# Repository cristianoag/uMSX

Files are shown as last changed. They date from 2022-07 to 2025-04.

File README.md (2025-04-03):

# uMSX
The uMSX is a MSX2+ FPGA implementation that basically mimics the 1ChipMSX (one of the first FPGA based MSX2+ one chip MSX computers commercially available).

**Please note that the PCB for this project was created by BCH and includes a label explicitly stating that commercial distribution of this work is prohibited. Unfortunately, there have been reports of unauthorized sales of this computer on platforms like Tindie. We kindly ask you to support and reward the original creators of this project, who have generously shared their work with the retro community, rather than those engaging in unauthorized distribution. Thank you for respecting the creators' efforts and intentions.**

The VHDL used is the well known [KDL PLD implementation for the MSX2+](https://github.com/gnogni/ocm-pld-dev) used by the vast majority of the FPGA based MSX computers known. The uMSX uses the first generation of the KDL VHDL source, also known by esemsx.

Based on the already obsolete (but relatively easy to find) Altera EP1C12 FPGA (specifically the EP1C12Q240C8N), the uMSX uses SMD based components (and a few PTH) in a nice compact form factor. It uses the 4 megabit EPCS4 active serial configuration flash memory to host the firmware and configure the FPGA chip at each time the circuit turns on.

A MT48LC16M16A2 SRAM chip offers memory for the computer, which also uses a few other components to implement the clock logic (NC7WV04P6X inverter and 21.47727 basic PTH crystal oscillator) and a 953B voltage detector and reset IC.

Heavily based on 0603 SMT resistance arrays, and other 0805 SMT components, the uMSX is a compact little OCM MSX that can be used to evolve your SMD soldering skills, challenge your knowledge of modern electronics applied to retro computing, and give you a lot of fun through the journey.

## Bill of Materials

### Main Board

<table><thead><tr><th>Qtd</th><th>Part</th><th>Value</th><th>Package</th><th>Type</th><th>Link</th></tr></thead><tbody><tr><td>1</td><td>uMSX main board PCB</td><td>NA</td><td>NA</td><td>NA</td><td><a href="https://www.pcbway.com/project/shareproject/uMSX_A_MSX2_FPGA_implementation_5feda574.html" title="Main Board">Main Board</a></td></tr><tr><td>1</td><td>Custom acrylic box</td><td>NA</td><td>NA</td><td>NA</td><td><a href="https://github.com/cristianoag/uMSX/tree/main/Cases/Acrylic" title="Acrylic Box">Acrylic Box</a></td></tr><tr><td>3</td><td>Nylon pcb standoff</td><td>20mm</td><td>M3</td><td>Black</td><td><a href="https://www.aliexpress.com/item/1005004311987482.html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" title="AliExpress">AliExpress</a></td></tr><tr><td>7</td><td>Nylon screw</td><td>10mm</td><td>M3</td><td>Black</td><td><a href="https://www.aliexpress.com/item/32976116532.html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" title="AliExpress">AliExpress</a></td></tr><tr><td>2</td><td>R106, R96</td><td>10R</td><td>M0805</td><td>SMD Resistor</td><td><a href="https://s.click.aliexpress.com/e/_DCLwtnV" title="AliExpress">AliExpress</a></td></tr><tr><td>1</td><td>R113</td><td>22R</td><td>M0805</td><td>SMD Resistor</td><td><a href="https://s.click.aliexpress.com/e/_DCLwtnV" title="AliExpress">AliExpress</a></td></tr><tr><td>2</td><td>R4, R6</td><td>100R</td><td>M0805</td><td>SMD Resistor</td><td><a href="https://s.click.aliexpress.com/e/_DCLwtnV" title="AliExpress">AliExpress</a></td></tr><tr><td>1</td><td>R7</td><td>1M</td><td>M0805</td><td>SMD Resistor</td><td><a href="https://s.click.aliexpress.com/e/_DCLwtnV" title="AliExpress">AliExpress</a></td></tr><tr><td>2</td><td>R8, R10</td><td>10K</td><td>M0805</td><td>SMD Resistor</td><td><a href="https://s.click.aliexpress.com/e/_DCLwtnV" title="AliExpress">AliExpress</a></td></tr><tr><td>3</td><td>R13A, R13B, R122</td><td>1K</td><td>M0805</td><td>SMD Resistor</td><td><a href="https://s.click.aliexpress.com/e/_DCLwtnV" title="AliExpress">AliExpress</a></td></tr><tr><td>26</td><td>RN133, RN97-101, RN103, RN105, RN108, RN110, RN112, RN114-121, RN123, RN126-127, RN129, RN131, RN135, RN152</td><td>100R</td><td>0603x4 CAY16</td><td>SMD Resistor Array</td><td><a href="https://s.click.aliexpress.com/e/_Ddf4wVz">AliExpress</a></td></tr><tr><td>8</td><td>RN95, RN107, RN109, RN124, RN128, RN130, RN132, RN134</td><td>200R</td><td>0603x4 CAY16</td><td>SMD Resistor Array</td><td><a href="https://s.click.aliexpress.com/e/_Ddf4wVz">AliExpress</a></td></tr><tr><td>5</td><td>RN16, RN111, RN125, RN12, RN13</td><td>1K</td><td>0603x4 CAY16</td><td>SMD Resistor Array</td><td><a href="https://s.click.aliexpress.com/e/_Ddf4wVz">AliExpress</a></td></tr><tr><td>1</td><td>RN94</td><td>10K</td><td>0603x4 CAY16</td><td>SMD Resistor Array</td><td><a href="https://s.click.aliexpress.com/e/_Ddf4wVz">AliExpress</a></td></tr><tr><td>1</td><td>C1</td><td>2.2uf</td><td>C0805</td><td>SMD Ceramic Capacitor</td><td><a href="https://s.click.aliexpress.com/e/_DlXxALh" title="AliExpress">AliExpress</a></td></tr><tr><td>23</td><td>C3-10, C13-15, C21, C23-25, C30-33, C35-37, C134</td><td>100nf</td><td>C0805</td><td>SMD Ceramic Capacitor</td><td><a href="https://s.click.aliexpress.com/e/_DlXxALh" title="AliExpress">AliExpress</a></td></tr><tr><td>2</td><td>C18-19</td><td>27pf</td><td>C0805</td><td>SMD Ceramic Capacitor</td><td><a href="https://s.click.aliexpress.com/e/_DlXxALh" title="AliExpress">AliExpress</a></td></tr><tr><td>8</td><td>C26-28, C18-19, CI10-11, CI16</td><td>220uf 10V</td><td>153CLV-0605</td><td>SMD Electrolytic Capacitor</td><td><a href="https://s.click.aliexpress.com/e/_DFFtZ2j">AliExpress</a></td></tr><tr><td>1</td><td>C34</td><td>4.7uf</td><td>C0805</td><td>SMD Ceramic Capacitor</td><td><a href="https://s.click.aliexpress.com/e/_DlXxALh" title="AliExpress">AliExpress</a></td></tr><tr><td>9</td><td>LED1-9</td><td>Any color</td><td>CHIP-LED0805</td><td>SMD LED</td><td><a href="https://s.click.aliexpress.com/e/_DlAhxEx" title="AliExpress">AliExpress</a></td></tr><tr><td>1</td><td>12V</td><td>1x2</td><td>12v pin to the cartridge board</td><td>Pin Header</td><td><a href="https://s.click.aliexpress.com/e/_DCc67kB" title="AliExpress">AliExpress</a></td></tr><tr><td>1</td><td>JP1</td><td>2x5</td><td>joystick connector</td><td>Pin Header</td><td><a href="https://s.click.aliexpress.com/e/_DeewpBd" title="AliExpress">AliExpress</a></td></tr><tr><td>1</td><td>JP2</td><td>1x2</td><td>on/off switch</td><td>Pin Header</td><td><a href="https://s.click.aliexpress.com/e/_DCc67kB" title="AliExpress">AliExpress</a></td></tr><tr><td>1</td><td>JP3</td><td>2x25</td><td>cartridge board connector</td><td>Pin Header</td><td><a href="https://s.click.aliexpress.com/e/_DeewpBd" title="AliExpress">AliExpress</a></td></tr><tr><td>1</td><td>JP4</td><td>2x5 (10 pin)</td><td>JTAG</td><td>Box Header Connector</td><td><a href="https://s.click.aliexpress.com/e/_DBTGWiB" title="AliExpress">AliExpress</a></td></tr><tr><td>1</td><td>JP5</td><td>3.5mm</td><td>Stereo</td><td>Audio Jack</td><td><a href="https://s.click.aliexpress.com/e/_DmHGVhZ" title="AliExpress">AliExpress</a></td></tr><tr><td>1</td><td>PS2</td><td>6P</td><td>keyboard connector</td><td>PS2</td><td><a href="https://s.click.aliexpress.com/e/_DnDTvyB" title="AliExpress">AliExpress</a></td></tr><tr><td>1</td><td>Q1</td><td>21.47727</td><td>HC49/S</td><td>PTH Crystal Oscillator</td><td><a href="https://s.click.aliexpress.com/e/_DCQxgXh" title="AliExpress">AliExpress</a></td></tr><tr><td>1</td><td>U1</td><td>EPCS4N</td><td>8-pin SOIC</td><td>Active Serial configuration flash</td><td><a href="https://www.aliexpress.com/item/32831351984.html?spm=a2g0o.order_list.0.0.d1da1802R1bdpb" title="AliExpress">AliExpress</a></td></tr><tr><td>1</td><td>U2</td><td>953BFP</td><td>8-pin SOIC</td><td>Voltage detector and reset</td><td><a href="https://s.click.aliexpress.com/e/_DkN7gub" title="AliExpress">AliExpress</a></td></tr><tr><td>1</td><td>U$1</td><td>EP1C12Q240C8N</td><td>240-Pin PQFP</td><td>Cyclone FPGA</td><td><a href="https://s.click.aliexpress.com/e/_DFt3Vzt" title="AliExpress">AliExpress</a></td></tr><tr><td>1</td><td>J1</td><td></td><td></td><td>Micro SD Slot</td><td><a href="https://s.click.aliexpress.com/e/_DCluFa3" title="AliExpress">AliExpress</a></td></tr><tr><td>1</td><td>J2</td><td>DC-005</td><td>Right Angle</td><td>Barrel Power Jack</td><td><a href="https://s.click.aliexpress.com/e/_DEC1UtH" title="">AliExpress</a></td></tr><tr><td>1</td><td>IC1</td><td>MT48LC16M16A2</td><td>TSOP54-400</td><td>SDRAM</td><td><a href="https://s.click.aliexpress.com/e/_DEzMg5d" title="AliExpress">AliExpress</a></td></tr><tr><td>1</td><td>IC2</td><td>3.3v AMS1117</td><td>SOT223</td><td>Voltage Regulator</td><td><a href="https://www.aliexpress.com/item/1005002664829046.html?spm=a2g0o.order_detail.0.0.1788f19c7Qk9pn" title="AliExpress">AliExpress</a></td></tr><tr><td>1</td><td>IC3</td><td>1.5v AMS1117</td><td>SOT223</td><td>Voltage Regulator</td><td><a href="https://www.aliexpress.com/item/1005002664829046.html?spm=a2g0o.order_detail.0.0.1788f19c7Qk9pn" title="AliExpress">AliExpress</a></td></tr><tr><td>1</td><td>IC5</td><td>NC7WZU04P6X</td><td>SOT65P210X110-6AN_SC88_SC70-6</td><td>Dual Unbuffered Inverter</td><td><a href="https://s.click.aliexpress.com/e/_Dmnx4mP" title="AliExpress">AliExpress</a></td></tr><tr><td>1</td><td>RCA</td><td>AV-8.4-5&nbsp;</td><td>RCA</td><td>RCA Connector</td><td><a href="https://www.aliexpress.com/item/1005002282617330.html?spm=a2g0o.order_list.0.0.d1da1802R1bdpb" title="AliExpress">AliExpress</a></td></tr><tr><td>1</td><td>F1</td><td>1.1A</td><td>1812</td><td>PPTC Fuse</td><td><a href="https://s.click.aliexpress.com/e/_Dl7GEh5" title="AliExpress">AliExpress</a></td></tr><tr><td>1</td><td>EDG-08 (SWITCH)</td><td>8 switches</td><td></td><td></td><td><a href="https://s.click.aliexpress.com/e/_DeIVL8P" title="AliExpress">AliExpress</a></td></tr><tr><td>1</td><td>S1 (Button)</td><td>6x6x7 </td><td>Push/Tactile</td><td>Reset Button</td><td><a href="https://s.click.aliexpress.com/e/_DnMVsvd" title="AliExpress">AliExpress</a></td></tr><tr><td>1</td><td>VGA</td><td>DB15</td><td>FEMALE&nbsp;SHORT</td><td>RIGHT ANGLE&nbsp;</td><td><a href="https://s.click.aliexpress.com/e/_DD6B9nl" title="AliExpress">AliExpress</a></td></tr><tr><td>1</td><td>ON/OFF  switch</td><td>2 pin</td><td>21x15</td><td>Boat switch</td><td><a href="https://s.click.aliexpress.com/e/_DFynEar" title="AliExpress">AliExpress</a></td></tr><tr><td>2</td><td>Jumper wire</td><td>Female</td><td>10cm</td><td>ON/OFF cables</td><td><a href="https://s.click.aliexpress.com/e/_DneiqIB" title="AliExpress">AliExpress</a></td></tr><tr><td>2</td><td>Spade Crimp Terminals and Sleeves</td><td>Female</td><td>4.8mm</td><td>(Buy the set)</td><td><a href="https://www.aliexpress.com/item/33048405492.html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" title="AliExpress">AliExpress</a></td></tr><tr><td>1</td><td>Socket Connector </td><td>Female</td><td>2.54MM Pitch</td><td>Joystick cable connector</td><td><a href="https://s.click.aliexpress.com/e/_DdWEL91" title="AliExpress">AliExpress</a></td></tr><tr><td>1</td><td>Flat Ribbon Cable</td><td>10P (10 pins)</td><td></td><td>Joystick cable</td><td><a href="https://s.click.aliexpress.com/e/_DegaOLh" title="AliExpress">AliExpress</a></td></tr><tr><td>1</td><td>DB9 male connector</td><td>9 pin</td><td></td><td>Joystick cable connector</td><td><a href="https://s.click.aliexpress.com/e/_DeWE3Fz" title="AliExpress">AliExpress</a></td></tr><tr><td>1</td><td>microSD/TF card</td><td>4GB</td><td></td><td>Memory card</td><td><a href="https://s.click.aliexpress.com/e/_DlS57W7" title="AliExpress">AliExpress</a></td></tr></tbody></table>

### Cartridge Board

<table><thead><tr><th>Qtd</th><th>Part</th><th>Value</th><th>Package</th><th>Type</th><th>Link</th></tr></thead><tbody><tr><td>1</td><td>uMSX cartridge board PCB</td><td>NA</td><td>NA</td><td>NA</td><td><a href="https://www.pcbway.com/project/shareproject/uMSX_A_MSX2_FPGA_implementation_5feda574.html" title="Cartridge Board">Cartridge Board</a></td></tr><tr><td>1</td><td>TMA_0512D</td><td>12V</td><td></td><td></td><td><a href="https://s.click.aliexpress.com/e/_DdxjSqf" title="AliExpress">AliExpress</a></td></tr><tr><td>2</td><td>Inductor</td><td>100uf</td><td>PTH</td><td></td><td><a href="https://s.click.aliexpress.com/e/_DmAOSjp" title="AliExpress">AliExpress</a></td></tr><tr><td>2</td><td>Electrolytic Capacitor</td><td>10uf/25V</td><td>153CLV-0605</td><td>SMD </td><td><a href="https://s.click.aliexpress.com/e/_Dmfm8KX" title="AliExpress">AliExpress</a></td></tr><tr><td>1</td><td>Electrolytic Capacitor</td><td>100uf/16V</td><td>153CLV-0605</td><td>SMD</td><td><a href="https://s.click.aliexpress.com/e/_Dmfm8KX" title="AliExpress">AliExpress</a></td></tr><tr><td>3</td><td>Ceramic Capacitor</td><td>100nf</td><td>C0805</td><td>SMD </td><td><a href="https://s.click.aliexpress.com/e/_DlXxALh" title="AliExpress">AliExpress</a></td></tr><tr><td>2</td><td>Ceramic Capacitor</td><td>4.7uf</td><td>C0805</td><td>SMD </td><td><a href="https://s.click.aliexpress.com/e/_DlXxALh" title="AliExpress">AliExpress</a></td></tr><tr><td>2</td><td>Resistor</td><td>2K</td><td>M0805</td><td>SMD</td><td><a href="https://s.click.aliexpress.com/e/_DCLwtnV" title="AliExpress">AliExpress</a></td></tr><tr><td>1</td><td>Main board connector</td><td>2x25</td><td></td><td>Pin Header</td><td><a href="https://s.click.aliexpress.com/e/_DeewpBd" title="AliExpress">AliExpress</a></td></tr><tr><td>2</td><td>Edge card connector</td><td>50P</td><td></td><td>Cartridge</td><td><a href="https://s.click.aliexpress.com/e/_DBeJZ51" title="AliExpress">AliExpress</a></td></tr><tr><td>4</td><td>PCB metal standoff</td><td>15-20mm</td><td>M3</td><td>Standoff</td><td><a href="https://s.click.aliexpress.com/e/_DdNrijD" title="AliExpress">AliExpress</a></td></tr><tr><td>4</td><td>Silicone cap</td><td>13mm</td><td>M3</td><td>Sleeve/cap</td><td><a href="https://s.click.aliexpress.com/e/_DlMdjAx" title="AliExpress">AliExpress</a></td></tr><tr><td>4</td><td>Nut</td><td></td><td>M3</td><td>Nut</td><td><a href="https://s.click.aliexpress.com/e/_Dk687gr" title="AliExpress">AliExpress</a></td></tr><tr><td>1</td><td>Main board cable</td><td>20cm</td><td>50P 2x25P</td><td>Flat cable</td><td><a href="https://www.aliexpress.com/item/1005001609304753.html?spm=a2g0o.order_list.0.0.21ef1802pojAjg" title="AliExpress">AliExpress</a></td></tr></tbody></table>

## References
* Original thread (in Spanish) with details about the project [uMSX: Clon MSX2+ FPGA](https://www.va-de-retro.com/foros/viewtopic.php?f=63&t=6655)

* Article (in English) with details on how to build, BoM, tips and tricks [Yet another FPGA based MSX (The uMSX)](https://theretrohacker.com/2022/07/08/yet-another-fpga-based-msx-the-umsx/)

* Youtube video (in Portuguese) with additional details [YouTube Video](https://www.youtube.com/watch?v=aj3B5qDagoM)

## License 

Open Hardware

This work is licensed under a [Creative Commons Attribution-NonCommercial-ShareAlike 4.0 International License](http://creativecommons.org/licenses/by-nc-sa/4.0/).

* If you remix, transform, or build upon the material, you must distribute your contributions under the same license as the original.
* You may not use the material for commercial purposes.
* You must give appropriate credit, provide a link to the license, and indicate if changes were made. You may do so in any reasonable manner, but not in any way that suggests the licensor endorses you or your use.

**ATTENTION**

This project was made for the retro community and not for commercial purposes. So only retro hardware forums and individual people can build this project.

THE SALE OF ANY PART OF THIS PROJECT WITHOUT EXPRESS AUTHORIZATION IS PROHIBITED!

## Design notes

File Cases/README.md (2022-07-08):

# Cases for the uMSX
* Acrylic - Corel draw 21 and 18 for case designs in 3mm acrylic. I also exported SVG files in case you have issues opening the Corel files. I opted for not use the cartridge box design.
* Caja uMSX FreeCad - This is a FreeCAD design for a case that can be 3D printed. 
* uMSX_case.zip - 3D printer case for the uMSX

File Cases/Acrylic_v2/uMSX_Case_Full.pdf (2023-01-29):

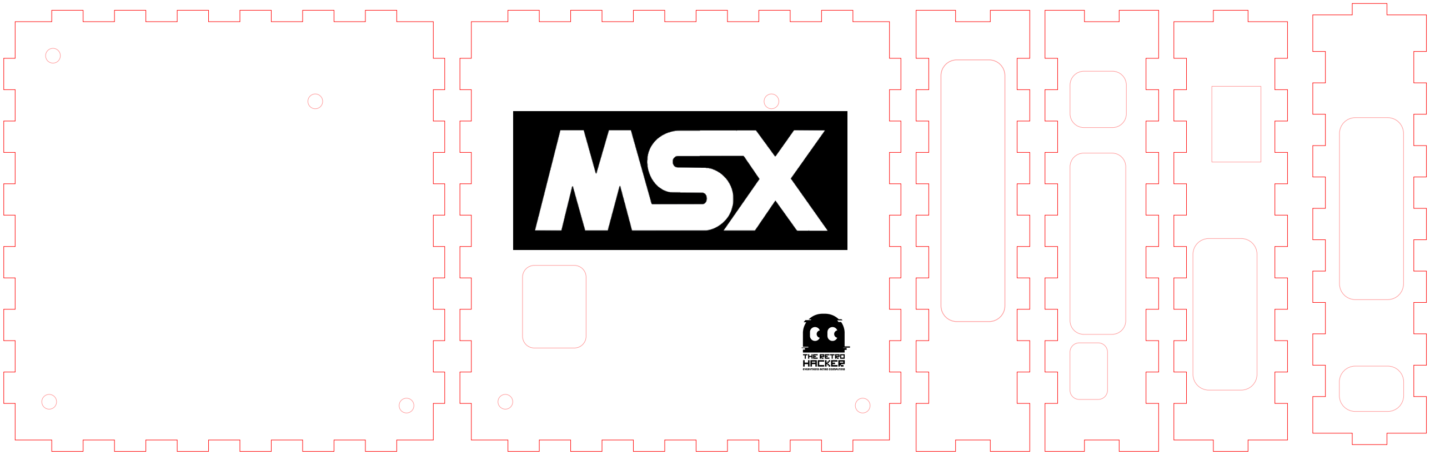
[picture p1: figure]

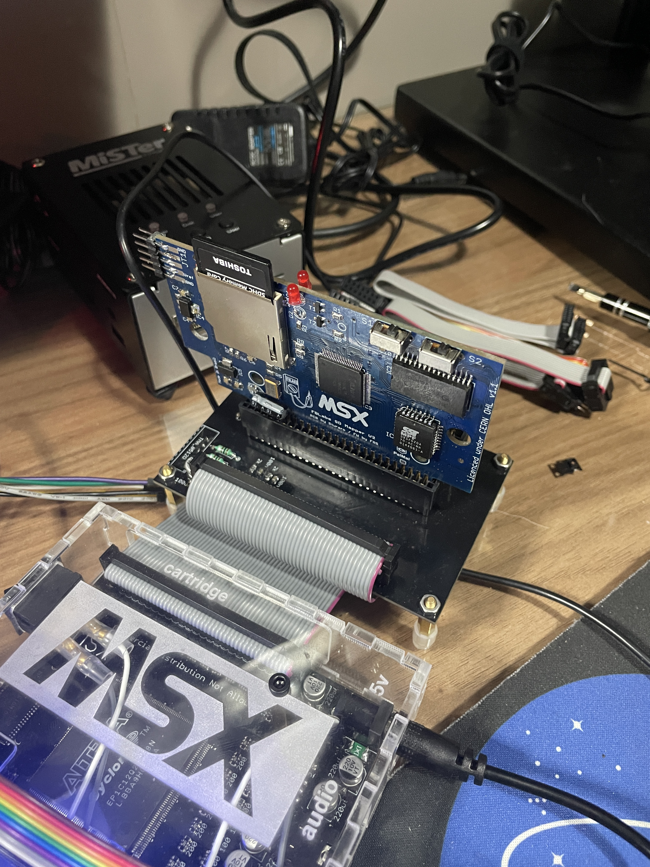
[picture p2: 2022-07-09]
Images/20220626_212402626_iOS.jpg

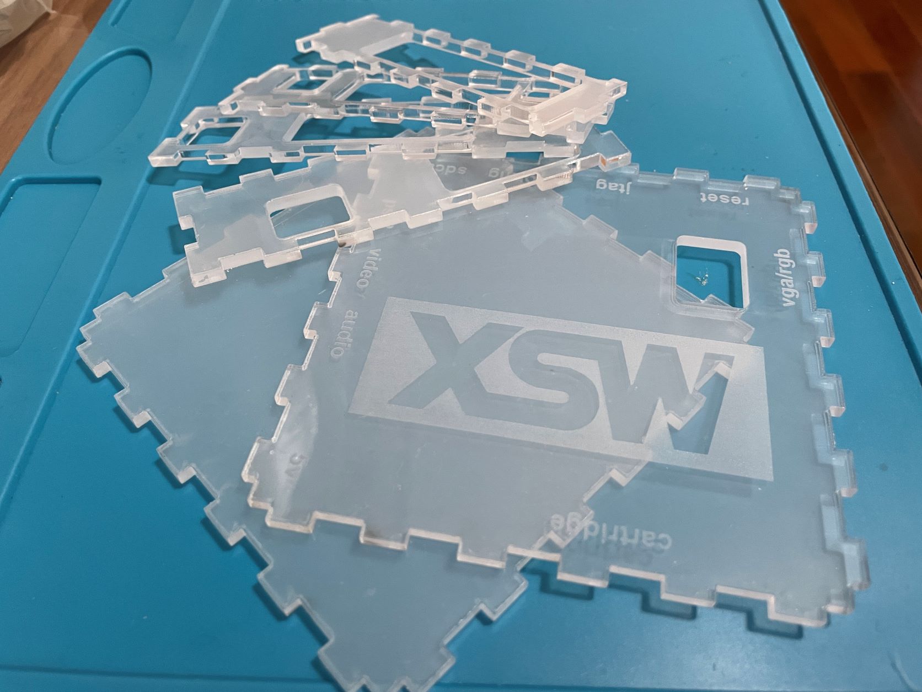
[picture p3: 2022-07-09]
Images/20220708_163719724_iOS.jpg

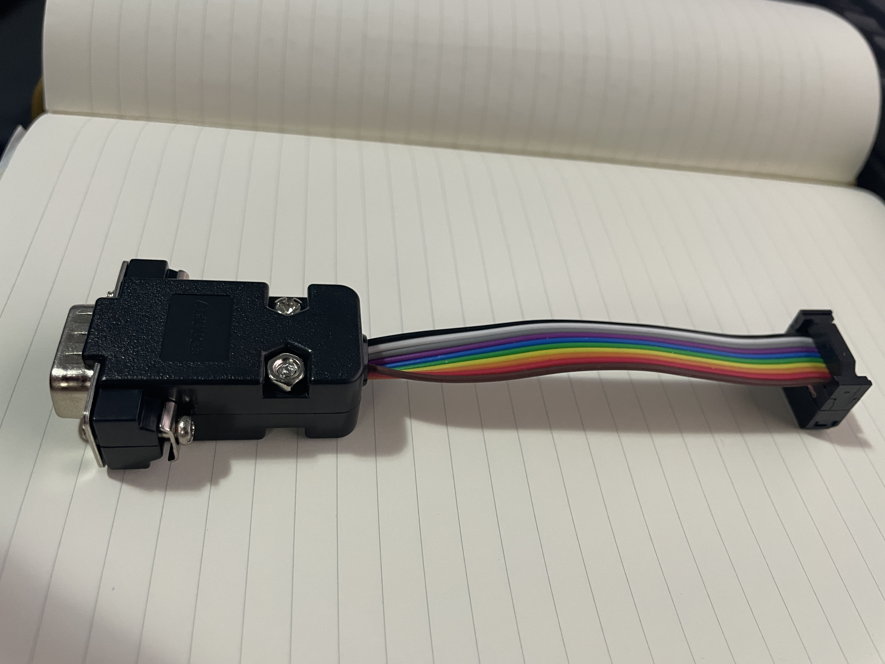
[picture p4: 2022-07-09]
Images/20220707_235009077_iOS.jpg

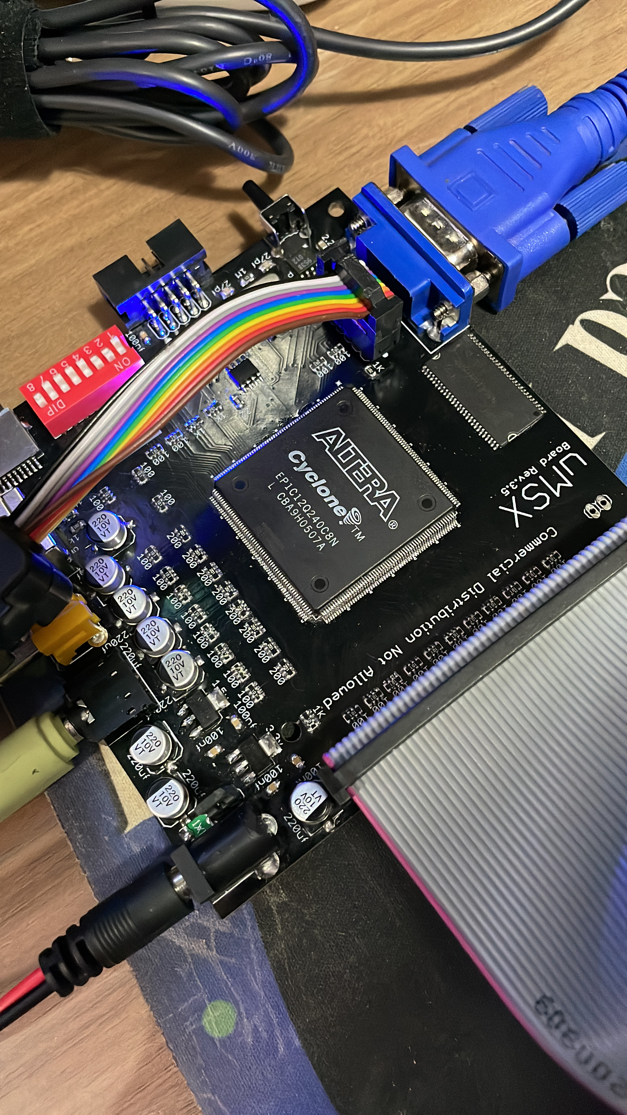
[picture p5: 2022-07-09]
Images/20220603_183352433_iOS.jpg

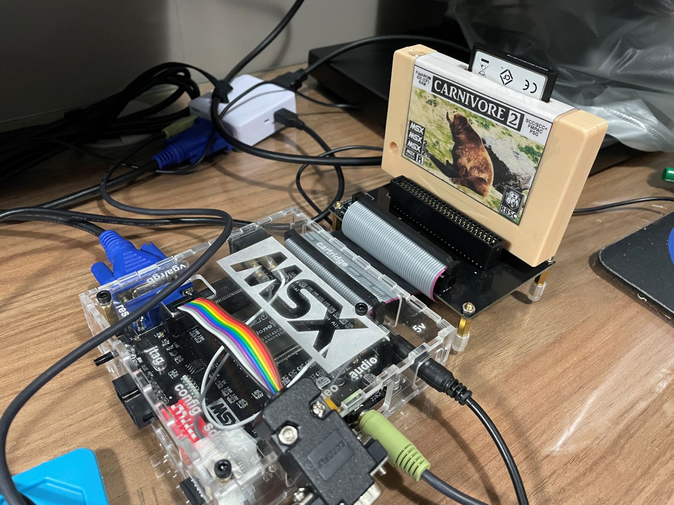
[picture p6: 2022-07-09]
Images/20220619_215049823_iOS.jpg

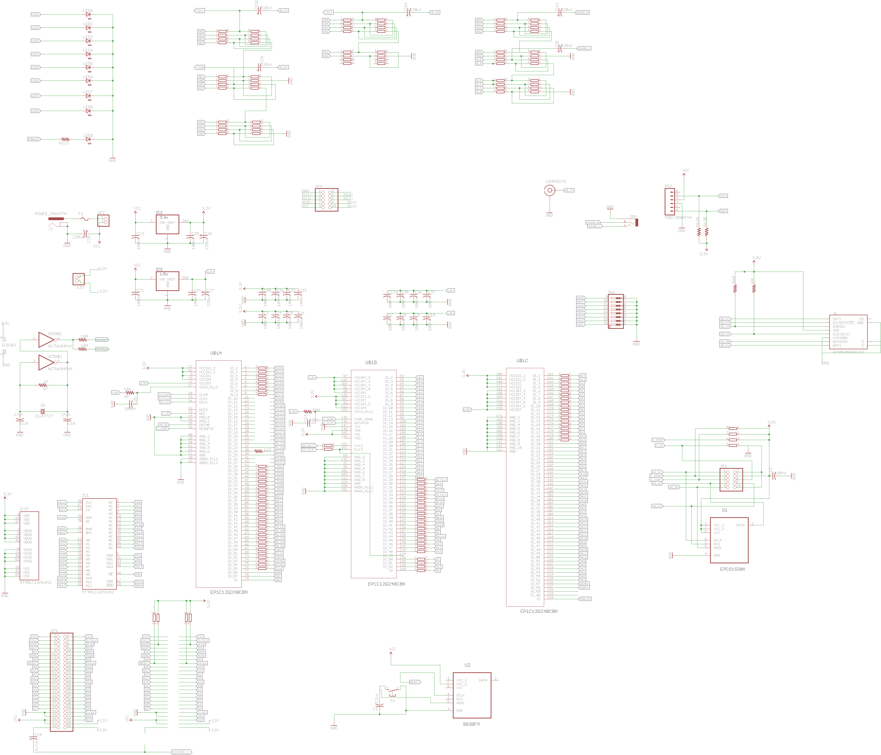
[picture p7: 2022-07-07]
Schemas/OCM_Schema.png

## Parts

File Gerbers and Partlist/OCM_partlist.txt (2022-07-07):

Partlist

EAGLE Version 6.5.0 Copyright (c) 1988-2013 CadSoft

Assembly variant: 

Part      Value              Package                        Library                     Position (mm)         Orientation

12V                          1X02                           pinhead                     (31.75 84.75)         R0
R106      10                 M0805                          resistor                    (46.22 18.49)         R90
R113      22                 M0805                          resistor                    (69.78 26.76)         R270
RN133     100                CAY16                          resistor-dil                (100.03 60.665)       R270
C1        2.2uf              C0805                          adafruit                    (36.67 10.07)         R90
C3        100nf              C0805                          adafruit                    (79.15 67.05)         MR0
C4        100nf              C0805                          adafruit                    (68.99 67.05)         MR270
C5        100nf              C0805                          adafruit                    (65.18 67.05)         MR270
C6        100nf              C0805                          adafruit                    (57.56 67.05)         MR270
C7        100nf              C0805                          adafruit                    (55.02 45.46)         MR180
C8        100nf              C0805                          adafruit                    (55.02 51.81)         MR180
C9        100nf              C0805                          adafruit                    (55.02 58.16)         MR180
C10       100nf              C0805                          adafruit                    (55.02 63.24)         MR180
C13       100nf              C0805                          adafruit                    (76.03 3.78)          R270
C14       100nf              C0805                          adafruit                    (62.465 75.705)       MR180
C15       100nf              C0805                          adafruit                    (41.18 18.99)         R90
C18       27pf               C0805                          adafruit                    (47.7 6.23)           R0
C19       27pf               C0805                          adafruit                    (57.37 6.23)          R180
C21       100nf              C0805                          adafruit                    (110.96 77.9)         R180
C23       100nf              C0805                          adafruit                    (106.61 88.86)        R180
C24       100nf              C0805                          adafruit                    (105.11 76.41)        R90
C25       100nf              C0805                          adafruit                    (100.72 88.01)        R90
C26       220uf              153CLV-0605                    adafruit                    (121.21 80.24)        R90
C27       220uf              153CLV-0605                    adafruit                    (118.31 71.76)        R90
C28       220uf              153CLV-0605                    adafruit                    (102.73 95.31)        R270
C30       100nf              C0805                          adafruit                    (57.56 41.65)         MR90
C31       100nf              C0805                          adafruit                    (63.91 41.65)         MR90
C32       100nf              C0805                          adafruit                    (74.07 41.65)         MR90
C33       100nf              C0805                          adafruit                    (79.15 41.65)         MR0
C34       4.7uf              C0805                          adafruit                    (39.69 83.28)         R180
C35       100nf              C0805                          adafruit                    (79.15 61.97)         MR0
C36       100nf              C0805                          adafruit                    (79.15 55.62)         MR0
C37       100nf              C0805                          adafruit                    (79.15 50.54)         MR0
C134      100nf              C0805                          adafruit                    (79.15 45.46)         MR0
CI8       220uf              153CLV-0605                    adafruit                    (107.96 56.19)        R180
CI9       220uf              153CLV-0605                    adafruit                    (108.92 41.37)        R180
CI10      220uf              153CLV-0605                    adafruit                    (103.71 34.54)        R180
CI11      220uf              153CLV-0605                    adafruit                    (107.96 48.99)        R180
CI16      220uf              153CLV-0605                    adafruit                    (108.17 63.49)        R180
COMPOSITE RCA                RCA                            uzebox                      (120.7 44.79)         R270
F1                           1812                           adafruit                    (120.07 86.58)        R180
IC1       MT48LC16M16A2-6A   TSOP54-400                     memory-micron               (32.41 54.35)         R270
IC2       3.3v               SOT223                         burr-brown                  (105.82 82.78)        R90
IC3       1.5v               SOT223                         burr-brown                  (108.42 71.05)        R90
IC5       NC7WV04P6X         SOT65P210X110-6AN_SC88_SC70-6  fairchild-tinylogic         (53.25 18.75)         R90 (ou SN74LVC2G04DCKR)
J1        ATTEND-MICROSD-112 ATTEND-112                     sd-mmc                      (111.75 4.75)         R0
J2        POWER_JACKPTH      POWER_JACK_PTH                 SparkFun-Connectors copy    (125.059103125 92.892028125) R90
JP1                          2X05                           pinhead                     (67.51 3.8)           R180
JP2                          1X02                           pinhead                     (113.68 86.23)        R180
JP3                          2X25                           pinhead                     (65.25 95.75)         R180
JP4                          2X05                           pinhead                     (43 29.5)             R270
JP5                          SPARKFUN-CONNECTORS_AUDIO-JACK zxuno_v41                   (121.5 60)            R180
LED1                         CHIP-LED0805                   adafruit                    (67.25 16.25)         R180
LED2                         CHIP-LED0805                   adafruit                    (69 16.25)            R180
LED3                         CHIP-LED0805                   adafruit                    (70.75 16.25)         R180
LED4                         CHIP-LED0805                   adafruit                    (72.5 16.25)          R180
LED5                         CHIP-LED0805                   adafruit                    (74.25 16.25)         R180
LED6                         CHIP-LED0805                   adafruit                    (76 16.25)            R180
LED7                         CHIP-LED0805                   adafruit                    (77.75 16.25)         R180
LED8                         CHIP-LED0805                   adafruit                    (79.5 16.25)          R180
LED9                         CHIP-LED0805                   adafruit                    (81.25 16.25)         R180
PS2       MINI-DIN6PTH       MINI-DIN6                      SparkFun-Connectors         (124.75 28.96)        R270
Q1        21.47727           HC49/S                         adafruit                    (53.09 11.35)         R180
R4        100                M0805                          resistor                    (49.49 18.67)         R270
R6        100                M0805                          resistor                    (56.45 18.83)         R90
R7        1M                 M0805                          resistor                    (52.66 6.07)          R0
R8        10k                M0805                          resistor                    (115.16 18.11)        R0
R10       10k                M0805                          resistor                    (120.93 18.14)        R180
R13A      1k                 M0805                          resistor                    (107.86 28.8)         R180
R13B      1k                 M0805                          resistor                    (107.86 25.99)        R180
R96       10                 M0805                          resistor                    (65.89 76.635)        MR270
R122      1K                 R0603                          adafruit                    (46.13 37.84)         R90
RN16      1K                 CAY16                          resistor-dil                (95.05 83.67)         R270
RN94      10K                CAY16                          resistor-dil                (62.1 13.59)          R270
RN95      200                CAY16                          resistor-dil                (93.1975 47.194375)   R270
RN97      100                CAY16                          resistor-dil                (44.75 87.25)         R0
RN98      100                CAY16                          resistor-dil                (48.75 30.25)         R0
RN99      100                CAY16                          resistor-dil                (49.135 87.25)        R0
RN100     100                CAY16                          resistor-dil                (53 30.25)            R0
RN101     100                CAY16                          resistor-dil                (53.52 87.25)         R0
RN103     100                CAY16                          resistor-dil                (57.905 87.25)        R0
RN105     100                CAY16                          resistor-dil                (62.29 87.25)         R0
RN107     200                CAY16                          resistor-dil                (93.084375 74.178125) R270
RN108     100                CAY16                          resistor-dil                (99.76 47.27)         R270
RN109     200                CAY16                          resistor-dil                (93.276875 42.273125) R270
RN110     100                CAY16                          resistor-dil                (66.675 87.25)        R0
RN111     1K                 CAY16                          resistor-dil                (74.329375 25.221875) R0
RN112     100                CAY16                          resistor-dil                (71.06 87.25)         R0
RN114     100                CAY16                          resistor-dil                (75.445 87.25)        R0
RN115     100                CAY16                          resistor-dil                (83.75 25.25)         R0
RN116     100                CAY16                          resistor-dil                (79.83 87.25)         R0
RN117     100                CAY16                          resistor-dil                (88.185 25.31)        R0
RN118     100                CAY16                          resistor-dil                (84.215 87.25)        R0
RN119     100                CAY16                          resistor-dil                (93.095 27.785)       R90
RN120     100                CAY16                          resistor-dil                (88.6 87.25)          R0
RN121     100                CAY16                          resistor-dil                (100.335 27.115)      R90
RN123     100                CAY16                          resistor-dil                (99.853125 42.249375) R270
RN124     200                CAY16                          resistor-dil                (93.005 51.675)       R270
RN125     1K                 CAY16                          resistor-dil                (79.06375 25.34875)   R0
RN126     100                CAY16                          resistor-dil                (99.76 51.81)         R270
RN127     100                CAY16                          resistor-dil                (99.734746875 74.093796875) R270
RN128     200                CAY16                          resistor-dil                (92.985625 69.4275)   R270
RN129     100                CAY16                          resistor-dil                (99.732221875 69.655228125) R270
RN130     200                CAY16                          resistor-dil                (93.005 64.915)       R270
RN131     100                CAY16                          resistor-dil                (99.9988125 65.01619375) R270
RN132     200                CAY16                          resistor-dil                (93.005 60.7)         R270
RN134     200                CAY16                          resistor-dil                (92.88 56.243125)     R270
RN135     100                CAY16                          resistor-dil                (99.72563125 56.380725) R270
RN152     100                CAY16                          resistor-dil                (93.25 34.785)        R90
S1                           B3F-31XX                       adafruit                    (40.64 3.55)          R0
SW1                          EDG-08                         special                     (90.62 6.05)          R0
U$1       EP1C12Q240C8N      QFP50P3460X3460X410-240N       Altera_By_element14_Batch_1 (67.72 54.35)         R90
U1        EPCS4N             SOIC127P600X175-8N             Altera_By_element14_Batch_1 (65.26 22.69)         R90
U2        953BFP             SOIC127P600X175-8N             Altera_By_element14_Batch_1 (42 10.5)             R90

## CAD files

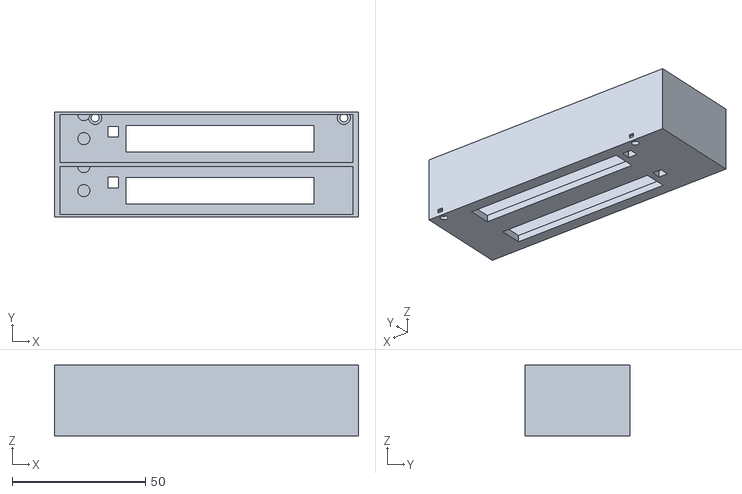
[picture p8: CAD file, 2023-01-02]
Cases/uMSX Slot Guide.stl
114.0 x 39.5 x 26.6

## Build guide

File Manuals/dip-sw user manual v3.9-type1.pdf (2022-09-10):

# DIP-SW User Manual

## for 1chipMSX, Zemmix Neo, SX-1 and related (Cyclone I series)

## OCM-PLD Pack v3.9 by KdL

DIP-SW | FUNCTION | STATUS | DESCRIPTION
| | OFF | Standard mode 3.58MHz
| 1 | CPU Clock | ON | Custom Speed mode 4.10MHz to 8.06MHz (10.74MHz on system bus) • Press [F12] key to change clock type (3.58MHz >> 5.37MHz >> Custom Speed) • The external clock is set on [Sync to CPU] by default • [Turbo Pana] is 5.37MHz like the original specification • A special hybrid clock [Turbo MegaSD] is enabled by default
| | | OFF / OFF | Composite / S-Video • 15kHz, 50Hz+60Hz, interlaced video signal
| 2 / 3 | Video Output | OFF / ON | RGB w/ Audio Out (a mono signal inside the video cable) • 15kHz, 50Hz+60Hz, interlaced video signal, requires a VGA to SCART cable
| | | ON / OFF | VGA Mode for LED TV or LED Display • Progressive video signal 31kHz / 50Hz+60Hz with the ability to set the pixel ratio 1:1 at 60Hz
| | | ON / ON | VGA+ Mode for CRT Monitor (legacy output) (hardware scanlines on Zemmix Neo) • Progressive video signal 31kHz / 50Hz+60Hz / SETSMART -D0 must be executed to force 60Hz
| | | OFF | External Slot-1 • Advised like default
| 4 | Cartridge Slot-1 | ON | Internal ESE-MegaSCC+ 1024kB (shared w/ the 2nd half of ESE-MegaSCC+ Slot-2) • External Slot-1 is disabled • Memo: the CMT toggle is [Scroll Lock] key (disabled by default)
| | | OFF / OFF | External Slot-2 • Advised like default
| 5 / 6 | Cartridge Slot-2 | OFF / ON | Internal ESE-MegaRAM ASCII-8K 1024kB • External Slot-2 is disabled
| | | ON / OFF | Internal ESE-MegaSCC+ 2048kB • External Slot-2 is disabled
| | | ON / ON | Internal ESE-MegaRAM ASCII-16K 2048kB • External Slot-2 is disabled
| 7 | Internal Mapper | OFF | Internal 2048kB RAM • Advised like default
| | | ON | Internal 4096kB RAM
| | | OFF | Disabled
| 8 | Internal MegaSD | ON | Enabled • Advised like default

## KdL Index! < https://gnogni.altervista.org >

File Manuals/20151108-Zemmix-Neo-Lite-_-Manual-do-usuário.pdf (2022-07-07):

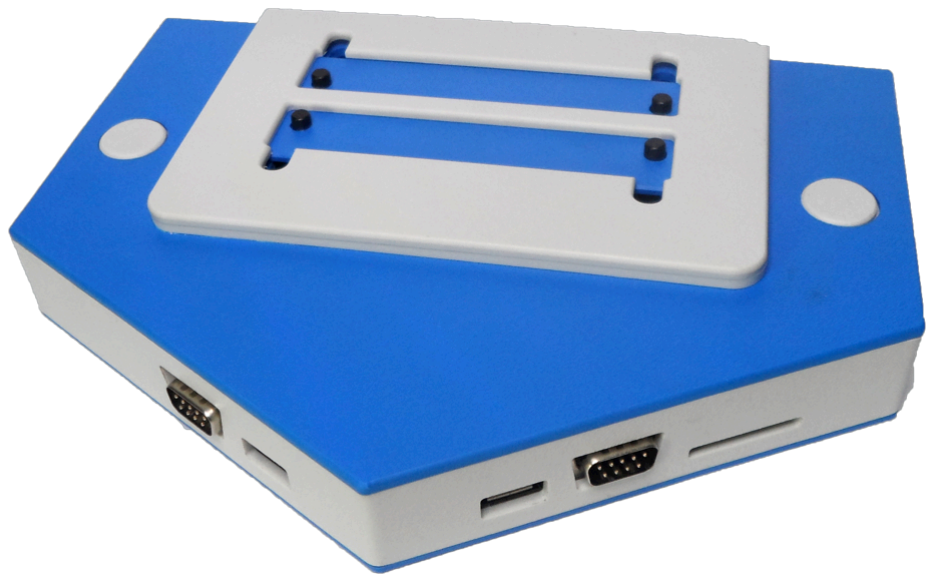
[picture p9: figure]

# Zemmix Neo Lite BR Edition Manual do Usuário

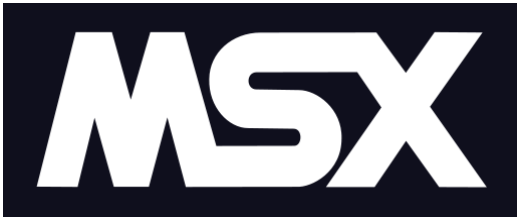
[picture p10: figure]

A obra Zemmix Neo Lite BR Edition - Manual do Usuário de Bruno Nazareth está licenciado com uma Licença Creative Commons -Atribuição-NãoComercial 4.0 Internacional. Baseado no trabalho disponível em mailto: brnazareth em gmail ponto com.

## Índice

## 1. O que é o MSX (definição da Wikipedia)

MSX é o nome de uma arquitetura padrão para computadores pessoais, lançada pela Microsoft em 16 de junho de 1983 e concebido por Kazuhiki Nishi, vice-presidente da Microsoft Japão e diretor da ASCII Corporation. Diz-se que a Microsoft liderou o projeto como uma tentativa de criar um padrão unificado para os fabricantes de hardware. Apesar do envolvimento da Microsoft, computadores baseados no MSX raramente são vistos nos Estados Unidos, mas foram populares em países como Japão, Oriente Médio, Brasil, União Soviética, Holanda, Espanha e menor volume em diversos países europeus. É difícil estimar quantos computadores MSX foram vendidos mundialmente, mas eventualmente 5 milhões de unidades foram vendidas apenas no Japão.

## 2. Sobre o Zemmix Neo

O Zemmix Neo é um hardware baseado na placa e código fonte do One Chip MSX (OCM). Basicamente, foram implementadas todas as funcionalidades do OCM e acrescentado um gerador de scanlines. Possui ainda suporte a teclados USB que emulem o padrão PS2.

## 3. Especificações

- Compatível com MSX2+
- Turbo de 8MHz
- 4 Megabytes de Mapper e 1 Megabyte de ESE-MegaRAM
- Saída VGA 15/31KHz
- Saídas de Vídeo Composto, S-Video
- Cartão SD (até 2GB em FAT16)
- Teclado PS/2 e USB
- 2 Slots para cartuchos
- Áudio Estéreo
- FM
- 1MB ESE-RAM SCC+
- Entrada para Cassete

## 4. Diagrama físico

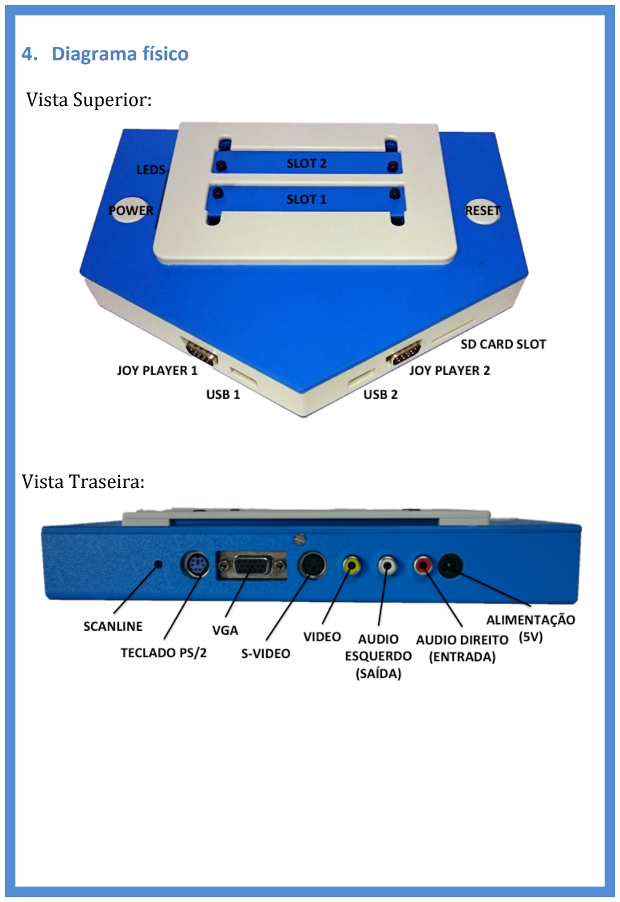
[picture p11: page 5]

Vista Superior:

Vista Traseira:

## 5. Como Ligar Seu Zemmix Neo

Antes de ligar seu Zemmix Neo, efetue as seguintes conexões:
1) Alimentação: a fonte deve ser de 5 volts e 2 ampéres. O polo positivo é o pino central.
2) Video: para melhor qualidade de imagem é recomendado utilizar a saída de video VGA. O Zemmix Neo, diferentemente de computadores MSX clássicos, suporta qualquer monitor equipados com este tipo de conector. Caso sua televisão não suporte essa entrada, prefira SVIDEO e por último o conector de VIDEO (amarelo).
3) Audio: conecte as saídas de audio direita e esquerda a uma caixa de som amplificada ou uma mesa/amplificador externo. Caso sua televisão não suporte audio stereo, utilize apenas o conector de saída de audio esquerdo (branco).
4) Teclado: a porta USB 2 suporta utilização de teclados que emulem o protocolo PS/2. Teclados reconhecidos como HID (Human Interface Device) não são suportados. Teclados padrão PS/2 também podem ser utilizados no conector traseiro do Zemmix Neo.
5) Cartuchos ROM ou Cartão SD: Insira os cartuchos ROM ou o cartão SD nos slots.

ATENÇÃO: Remover qualquer conexão ou dispositivo de armazenamento com seu Zemmix Neo ligado pode danifica-lo. Desligue sempre o Zemmix Neo antes de fazer qualquer alteração.

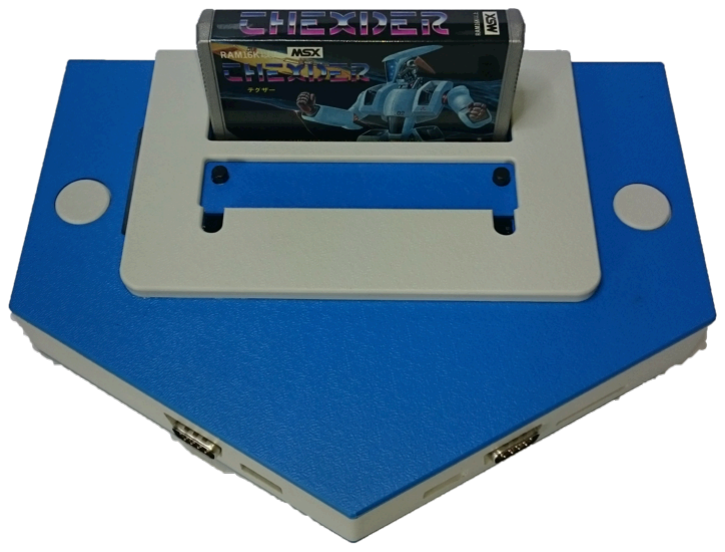
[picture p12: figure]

## 6. Configurações de Dip Switches

Switch | Função | Estado | Explicação
SW1 | Velocidade CPU | Desligado | Modo 3,58 MHz
| | Ligado | Velocidade personalizada (8,06MHz) - Modo TurboPANA é 5,37MHz - Turbo MegaSD é habilitado como padrão
SW2/SW3 | Saída de Vídeo | Desligado/Desligado | Modo Video Composto/S-Video (15KHz Interlaçado, 50/60Hz)
| | Desligado/Ligado | RGB-Audio Mono (15KHz, vídeo Interlaçado, 50/60Hz, SCART, Aúdio mono no conector VGA)
| | Ligado/Desligado | VGA brilho normal (31KHz progressivo, 60Hz somente)
| | Ligado/Ligado | VGA com scanlines (31KHz progressivo, 50/60Hz)
SW4 | Configuração Slot 1 | Desligado | Usar Slot 1 externo
| | Ligado | Modo ESE MegaSCC+ interna (1024KB) - Slot 1 externo desabilitado
SW5/SW6 | Configuração Slot 2 | Desligado/Desligado | Usar Slot 2 externo
| | Desligado/Ligado | Modo ESE MegaRAM interna [ASCII-8KB-BANK] (1024KB) - Slot 2 externo desabilitado
| | Ligado/Desligado | Modo ESE MegaSCC+ interna (1024KB) - Slot 2 externo desabilitado
| | Ligado/Ligado | Modo ESE MegaRAM interna [ASCII-16KB-BANK] (1024KB) - Slot 2 externo desabilitado
SW7 | Memory Mapper | Desligado | RAM interna de 2048KB
| | Ligado | RAM interna de 4096KB
SW8 | Cartão SD | Desligado | Desabilitado
| | Ligado | Ligado

Exemplo de dip switches (recomendada por padrão):
- Ligadas: 1, 2, 3 e 8
- Desligadas: 4, 5, 6, 7

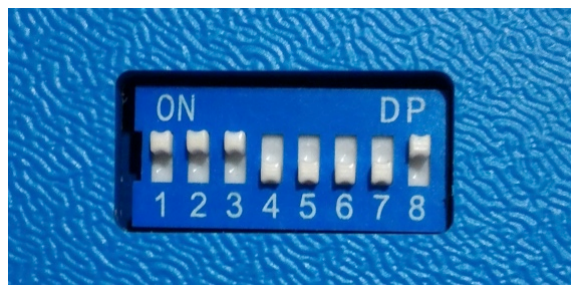
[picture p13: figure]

## 7. Atalhos de teclado

O Zemmix Neo suporta teclados PS/2 ou USB que emule comandos PS/2. Algumas teclas de um MSX tradicional foram mapeadas para serem adequadas aos teclados modernos. Existem também algumas teclas e combinações que podem ser utilizadas para alterar as configurações de hardware do Zemmix Neo:

Tecla ou Combinação | Função
END | Tecla STOP do MSX.
ALT | Tecla GRAPH do MSX.
WIN | Tecla SPACE do MSX.
F6 | Tecla GRAPH do MSX.
F7 | Tecla KANA do MSX.
F8 | Tecla SELECT do MSX.
F9 | Aumenta o volume do PSG.
SHIFT + F9 | Abaixa o volume do PSG.
F10 | Aumenta o volume do SCC.
SHIFT + F10 | Abaixa o volume do SCC.
F11 | Aumenta o volume do OPL.
SHIFT + F11 | Abaixa o volume do OPL.
PAGE UP | Aumenta o volume geral.
PAGE DOWN | Abaixa o volume geral.
F12 | Altera o clock da CPU entre 3 valores: 3,58MHz, 5,37MHz, ou Personalizado 8MHz.
PRINTSCREEN | Altera o tipo de saída de vídeo na sequencia: CVBS/S-Video, SCART, VGA 31KHz, VGA+ 31KHz.
SHIFT + PRINTSCREEN | Altera o tipo de saída de vídeo na sequencia: VGA+ 31KHz , VGA 31KHz, SCART, CVBS/S-Video.
SCROLL LOCK | Ativa ou desativa o modo Cassete.
SHIFT + F12 | Altera a configuração do SLOT 1: externo/SCC+.
SHIFT + SCROLL LOCK | Altera a configuração do SLOT 2: externo/ASCII8/SCC+/ASCII16.

## 8. Leds de Status

Os LEDs indicam algumas configurações atuais. Os LEDs Verdes são numerados de 1 a 8 no sentido de cima para baixo e o Vermelho é o 9. Durante os ajustes de volume os LEDs são usados para indicar o nível de volume, no estilo Bargraph. Após um tempo os LEDs voltam à indicar as configurações atuais:

Led | Status | Status
1 | Piscando | Atividade no Cartão SD ou memória Flash.
2 | Apagado Aceso | Memória Mapper a 2MB. Memoria Mapper a 4MB.
3/4 | Apagado/Apagado Apagado/Aceso Aceso/Apagado Aceso/Aceso | SLOT 2 Externo Ativo ESE-MegaRAM ASCII 8K Ativa ESE-MegaSCC+ Ativa ESE-MegaRAM ASCII 16K Ativa
5 | Apagado Aceso | SLOT 1 Externo Ativo ESE-SCC+ Ativa
6/7 | Apagado/Apagado Apagado/Aceso Aceso/Apagado Aceso/Aceso | Modo Vídeo Composto / S-Video Modo RGB-Audio(SCART) Modo VGA brilho normal Modo VGA com scanlines
8/9 | Apagado/Apagado Apagado/Aceso Aceso/Apagado | Clock de 3.58 MHz Clock de 5.37 MHz Clock Custom

No teclado os LEDs também são indicadores para alguns estados:
- LED Scroll Lock: modo cassete ativado;
- LED: Num Lock: modo Kana ativado.

## 9. Execução de Programas no Zemmix Neo

## 9.1.Como usar cartuchos ROM MSX

Os dois slots do Zemmix Neo podem ser utilizados para executar cartuchos ROM. Para ativar o slot 1 é necessário manter a dip switch 4 desligada. Para ativar o slot 2, desligue as dip switches 5 e 6.
Após alterar as configurações das dip switches, basta inserir o cartucho e ligar o Zemmix Neo.

ATENÇÃO: Não insira ou remova os cartuchos com o Zemmix Neo Ligado!

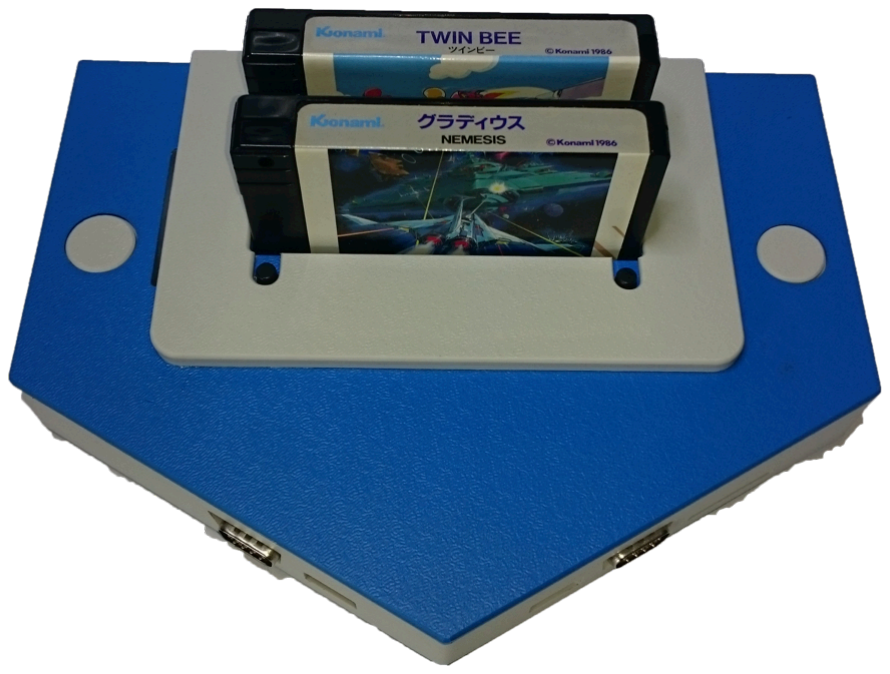
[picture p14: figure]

## 9.2.Uso de drive externo

Além de alterar as dip switches para habilitar os slots para Interface de drive externo, é necessário ainda desabilitar o leitor de cartões SD que pode interferir no funcionamento:

1. Desligue a dip switch 8. (Quando a dip switch 8 está ligada significa habilitar o cartão de leitor SD e pode gerar erros com o FDD)
2. Insira a interface de drive no slot - Pode ser utilizado qualquer slot. Certifique-se que está bem encaixado.
3. Ligar o Zemmix Neo

Caso tenha um disco inserido no drive, ele será lido. Caso contrário será exibida a tela de Disk BASIC.

## 9.3.Uso de gravador de dados

É possível ligar um gravador de fitas cassete ao Zemmix Neo:

1. Desligue a dip switch 8 para usar o gravador de dados.
2. Ligar o Zemmix Neo e apertar a tecla Scroll Lock uma vez.
3. Ligar o gravador no conector RCA VERMELHO. Esse conector é compartilhado como entrada e saída K7.
4. Inserir o comando adequado.

Após a exibição da tela de BASIC, entre com o comando CLOAD (Pode ser utilizado BLOAD, RUN de acordo com o manual de instruções da fita cassete). Não existe conexão “remote” no Zemmix Neo, portanto é requerido pressionar os botões play/stop/record no gravador manualmente.

## 9.4.Uso de cartão SD

É possível utilizar cartões SD como armazenamento de programas executáveis, arquivos ROM, arquivos DSK e etc. O Zemmix Neo aceita cartões de no máximo 2GB formatados apenas em FAT16.

ATENÇÃO: O Zemmix Neo não é compatível com cartões SDHC e não suporta cartões maiores que 2GB.

1. Certifique-se que o cartão utilizado é compatível com o Zemmix Neo.
2. Ligue a dip switch 8 com o Zemmix Neo desligado.
3. Insira o cartão SD no Zemmix Neo. Será escutado um clique quando o cartão estiver conectado corretamente.

4. Use o cartão SD como um dispositivo de armazenamento em massa.

Após a inicialização, será exibida a tela do Disk BASIC. Podem ser utilizados os comandos de BASIC para manipulação de arquivos (FILES, SAVE, LOAD, etc…) para controlar o cartão SD. Normalmente, o cartão SD é reconhecido como drive A. Caso exista uma interface de disco externa conectada, o cartão será reconhecido como drive C.

5. Uso do MSX-DOS2: Os arquivos MSXDOS2.SYS e COMMAND2.COM podem ser copiados para o cartão SD. É possível encontrar esses arquivos em repositórios na Internet.
6. Uso do ROMLOAD: Arquivos ROM podem ser executados através do comando romload <arquivo .rom>. Os arquivos ROM podem ser executados em conjunto com a emulação da SCC+ e MegaRAM controladas através das dip switches 4, 5 e 6.
7. Uso do MGLOCM: Arquivos ROM podem ser executados através do comando mglocm <arquivo .rom> com configuração automática dos periféricos internos.

Para remover o cartão SD, desligue o Zemmix Neo e pressione o cartão. Será ouvido um clique quando o cartão for ejetado.

ATENÇÃO: O LED 8 piscará quando o cartão SD estiver em uso. O cartão pode ser danificado se removido ou o Zemmix Neo com o cartão estiver em uso. Verifique se o cartão está em uso antes de remove-lo.

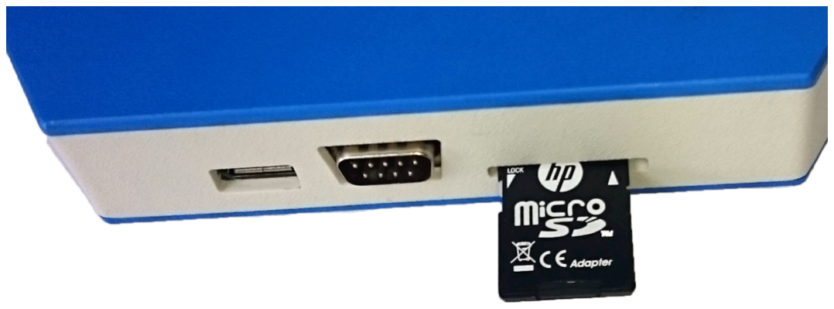
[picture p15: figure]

## 9.5.Execução de discos de jogos (Uso do ep.com)

### 1. Jogos multi-disco (Exemplo: YS 2)

Copie as imagens de disco YS21.DSK e YS22.DSK para o cartão SD (no mesmo diretório).

Execute o comando “ep YS2*.DSK /b /r” na linha de comando.

É possível alterar o disco com o atalho F7+Enter e depois pressione o número do disco (0 a 9).

### 2. Jogos de um disco como Age of Discovery (Jogos da Koei)

Acrescente as seguintes linhas ao Autoexec.bat:

set shell=b:\command.com
path b:\

Copie o arquivo Dai.dsk (imagem do Age of Discovery) e o reboot.com para o cartão SD.

Execute o comando “ep DAI.DSK a:” e execute “reboot.com” a partir do drive A.

É possível salvar status dos jogos em disco. Também pode utilizar uma PAC ou FM-PAC. Alguns jogos que verificam “S-RAM” não podem ser salvos na PAC ou FM-PAC.

ATENÇÃO: Este método de troca de discos não funciona para jogos do tipo “3 Kingdoms”.

### 3. Snatcher, SD-Snatcher ou Konami Game Collections

Ligue a dip switch 5, desligue a dip switch 6 (ESE-SCC+) no Zemmix Neo e execute o comando ep para o arquivo em questão.

## 9.6.Execução de jogos Megarom

1. Usar o romload.com para jogos megarom.
Execute o comando “romload ROM_NAME.rom /r /s” com a dip switch 5 ligada e a 6 desligada.

Se o arquivo ROM não for executado, é possível abrir o arquivo romload.lst para validar as opções do romload. O romload.com possui uma configuração interna para permitir a execução de Konami SCC, Konami4 (Metal Gear 1 e 2, Maze of Galious, etc…), ASCII (Bubble Bobble), ASC16K (Aleste).
2. Usar Ngload para carregar jogos megarom.
Altere as dip switches no Zemmix Neo para cada tipo de cartucho:
5 desligado, 6 ligado: ESE-ASCII 8K
5 ligado, 6 desligado: ESE-SCC+
5 ligado, 6 ligado: ESE-ASCII 16K

Execute o comando “ngload ROM_NAME /r”.

É necessário alterar a extensão do arquivo ROM. Por exemplo, Konami SCC deve ser alterado para SCK/SKN/ROM, Konami 4 alterado para KNM, ASC 8k alterado para 8K e ASC 16K alterado para 16K.
É necessário alterar a mapper megarom em conjunto com as dip switches do Zemmix Neo.

### 3. Jogos Koei 4M

Desligue a dip switch 5 e ligue a 6 (ESE-ASCII 8K).

Ao executar uma ROM Koei 4M será exibido na tela “S-RAM check”. É possível executar o jogo e salvar na PAC ou FM-PAC. Não funciona para todos os jogos da Koei.

### 4. MGLOCM

Outra opção é usar o utilitário MGLOCM.COM. Deixe as dip switches 4, 5 e 6 desligadas, execute o comando “mglocm ROMFILE.ROM” e o utilitário irá reconhecer o formato da ROM, configurar os slots de acordo com o necessário e executar o jogo.
ATENÇÃO: Ao executar o MGLOCM os slots externos podem ser desativados para a ativação dos periféricos internos, causando travamento se houver algum cartucho de armazenamento em massa sendo utilizado.

## 10.Solução de problemas

Verifique essas soluções caso encontre problemas.

Problema: O Zemmix Neo não liga.
- O cabo de força está ligado corretamente?
- A Fonte é compatível? O Zemmix Neo suporta alimentação de 5 volts com até 2 ampéres e polo positivo no centro. Apesar de funcionar, não é recomendado a alimentação pelas portas USB pois não existem proteções contra surtos de energia nessas entradas.

O Zemmix Neo está ligado mas não exibe nada na tela.
- Está ligado corretamente na TV? O conector de video no Zemmix Neo é igual ao da TV (amarelo).
- O conector/cabo não está com defeito?
- A lâmpada de status acende corretamente?
- Alguns monitores VGA não suportam a saída do Zemmix neo. Tente utilizar as saídas S-video ou A/V.
- Através das combinações das dip switches 2 e 3 é possível trocar os modos de exibição. Se a tela não exibir nada e não for detectado um problema de hardware, verifique as configurações das dip switches.

ATENÇÃO: Não utilize mais de uma saída de video simultaneamente. Isso pode danificar seu Zemmix Neo.

O teclado não funciona
- O teclado está conectado na porta PS/2 ou na porta USB da direita? O conector USB da esquerda não pode ser utilizado para teclado. A maioria dos teclados USB podem ser utilizados com o Zemmix Neo, mas alguns teclados não são compatíveis com a conexão PS/2. Tente um outro teclado.
- O Zemmix Neo utiliza algum teclado especial?
O Zemmix Neo utiliza o teclado padrão ABNT. Se forem pressionadas múltiplas teclas, algumas podem ser reconhecidas erroneamente.

O cartucho de ROM não funciona.
- O cartucho não está sujo? Limpe o cartucho e o slot se o cartucho não funcionar.
- Alguns cartuchos precisam ser iniciados com a tecla shift pressionada.

- Mesmo se for inserido o cartucho no Zemmix Neo com as configurações das dip switches corretas, pode ser exibida a tela do BASIC ou gráficos distorcidos. Pode ser por causa de sujeira no slot para cartuchos. É necessário proceder com a limpeza do slot.
Para limpar o slot, pode utilizar um cotonete embebido com um pouco de álcool isopropílico ou etanol. Espere secar antes de utilizar o slot.

Programa no disco não funciona
- O disco não está danificado?
- O Software no disco é compatível com MSX/MSX2/MSX2+? O Zemmix Neo é compatível com MSX2+, entretanto, não é possível garantir 100% de compatibilidade. Software de Turbo-r não é compatível.
- A leitura de discos pode ser afetada caso a cabeça de leitura esteja suja. É necessário utilizar um disco de limpeza para corrigir o problema.

Cartão SD não funciona
- A dip switch 8 está desligada? O Zemmix Neo pode ter sido enviado da “fábrica” com a dip switch desligada.
- O cartão está formatado com FAT16? Utilize este programa para formatar o cartão SD (o programa de formatação do Windows 7 pode causar alguns problemas).
http://panasonic.jp/support/audio/sd/download/sd_formatter.html

Joystick não funciona.
- O Joystick (joypad) é compatível com MSX? O conector é idêntico ao Sega Genesis/Mega Drive, mas não é compatível.

Não é possível escutar nada.
- A saída de áudio está ligada na TV? A entrada/saída de áudio também é utilizada com o gravador de dados. Se a SCC ou outros cartuchos de áudio estiverem em uso, ligue apenas o conector branco.

## 11.Links úteis

KdL Index!
Firmwares e Roms para o Zemmix Neo http://gnogni.altervista.org/

MSX.ORG Download Database/ROM Utilities
mglOCM
http://www.msx.org/downloads/utilities/rom

MSX Banzai!
MSX-DOS2, EP, FDLoad, ROMLOAD... http://msxbanzai.tni.nl/computers/ese3.html

Documentação do Projeto por Luis Fernando Zanoto
http://www.optotech.net.br/msx/zemmix_neo/

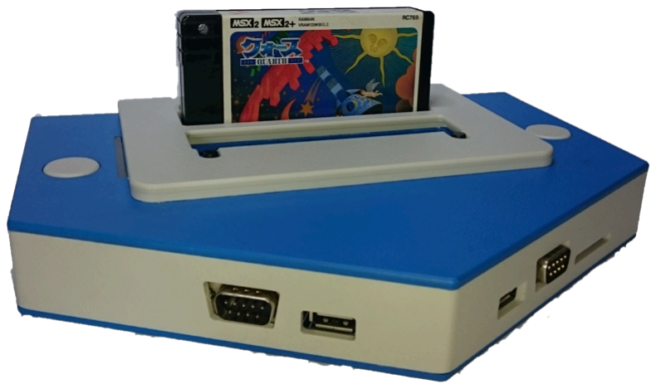
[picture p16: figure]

## Agradecimentos especiais para:

D4 Enterprise/ 1chipMSX
Retroteam Neo / Zemmix Neo

Projeto Zemmix Neo Lite BR Edition: Luis Fernando Luca
Luciano Sturaro
Fabio Belavenuto

Tradução Manual em Português: Bruno Nazareth

Imagens:
Rudolph Gutlich

E toda comunidade MSX que apoiou o projeto.

Novembro de 2015

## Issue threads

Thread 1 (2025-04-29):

STL model - case for uMSX

serperus, 2025-04-29:
Hi Cristiano,

Could you please add a hole for VGA connector? Not a bad idea, I think :)

Many thanks

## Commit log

2023-01-02 cartridge guide
    [uMSX Slot Guide.stl]
2023-01-29 New acrylic case
2024-03-25 Including the BOM directly to the README file
